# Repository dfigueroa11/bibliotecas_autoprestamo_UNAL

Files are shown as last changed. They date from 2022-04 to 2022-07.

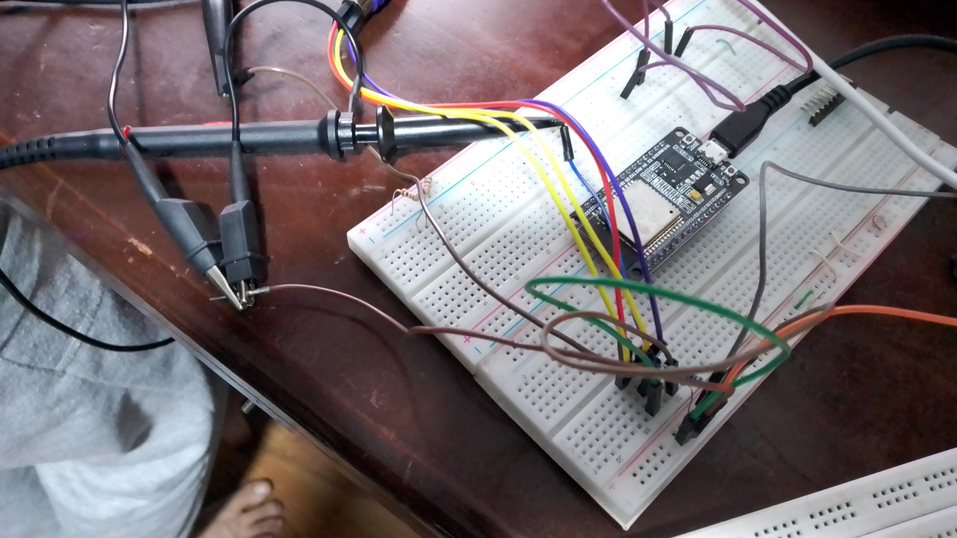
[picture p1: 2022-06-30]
images/teclado_ps_2_prueba.jpg

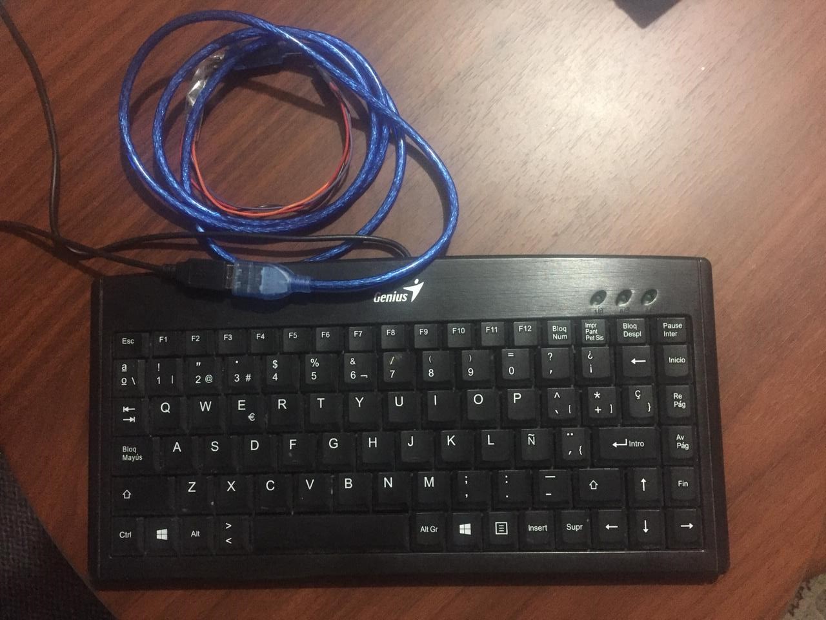
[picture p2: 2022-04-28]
images/reclado_prueba.jpeg

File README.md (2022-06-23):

# Autoprestamo de libros

Sistema de automatización de préstamo y devolución de Libros de las Bibliote dentro del campus de la Universidad Nacional de Colombia, incorporando la conexión entre puntos de prestamo y facilitando el proceso que a la fecha se implementa. El sistema tiene como objetivo principal reducir construir un sistema que pueda ser escalable y replicable de forma más economica.

Integrantes: 
* Maria Alejandra Salgado Herrera
* Emmanuel David Correa Morales
* Ferdy Eduardo Larrotta Ruiz
* Danny Esteban Portela Robayo
* Diego Alejandro Figueroa Del Castillo

## Organización del repositorio

### En la carpeta "[Sensibilizador_PCB](https://github.com/dfigueroa11/bibliotecas_autoprestamo_UNAL/tree/main/Sensibilizador_PCB)" se encuentran los diseños y esquemáticos llevados a cabo en el diseño del Sensibilizador del sistema.
### En la carpeta "[esquematico_ESP32](https://github.com/dfigueroa11/bibliotecas_autoprestamo_UNAL/tree/main/esquematico_ESP32)" se encuentran los diseños y esquemáticos llevados a cabo en el diseño del circuito logico y de control del sistema.
### "[Micropython](https://github.com/dfigueroa11/bibliotecas_autoprestamo_UNAL/tree/main/Micropython)" contiene los scripts utilizados para programar el microcontrolador de la solución.
### En "[Diseno_carcasa](https://github.com/dfigueroa11/bibliotecas_autoprestamo_UNAL/tree/main/Diseno_carcasa)" se encuentran los modelos 3D, planos, DXFs y consideraciones físicas para la carcasa. 
### "[Lista_materiales.xlsx](https://github.com/dfigueroa11/bibliotecas_autoprestamo_UNAL/blob/main/Lista_materiales.xlsx)" contiene la lista de materiales necesarios para el desarrollo del prototipo. 
### "[images](https://github.com/dfigueroa11/bibliotecas_autoprestamo_UNAL/tree/main/images)" almacena las imágenes utilizadas en la documentación y en los archivos readme de cada sección.

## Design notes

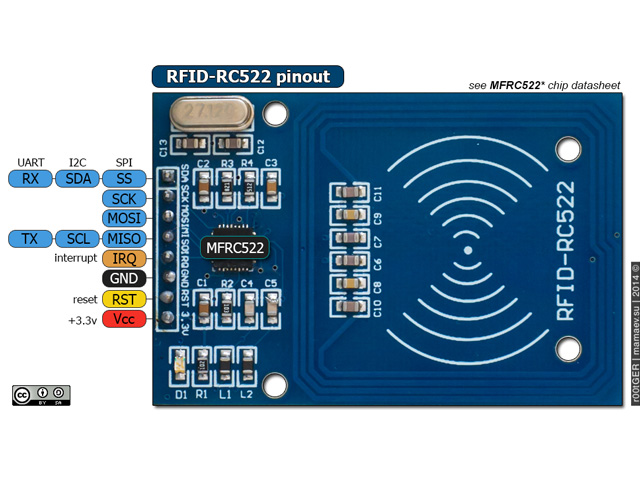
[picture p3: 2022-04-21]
images/modulo-rfid-c522.jpg

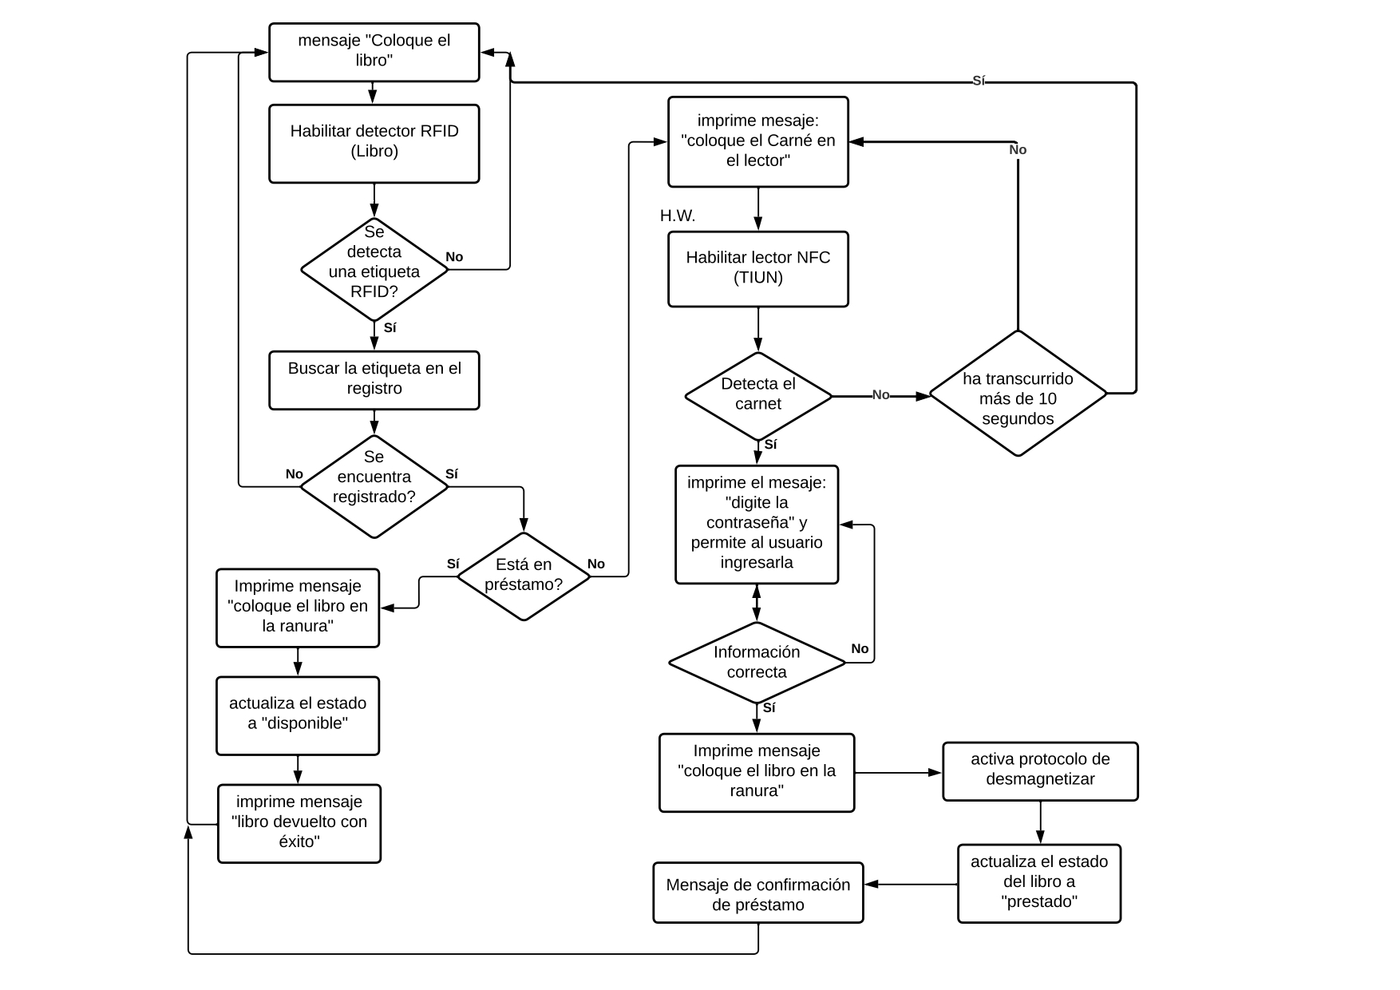
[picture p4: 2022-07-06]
images/diagrama_funcionamiento.jpg

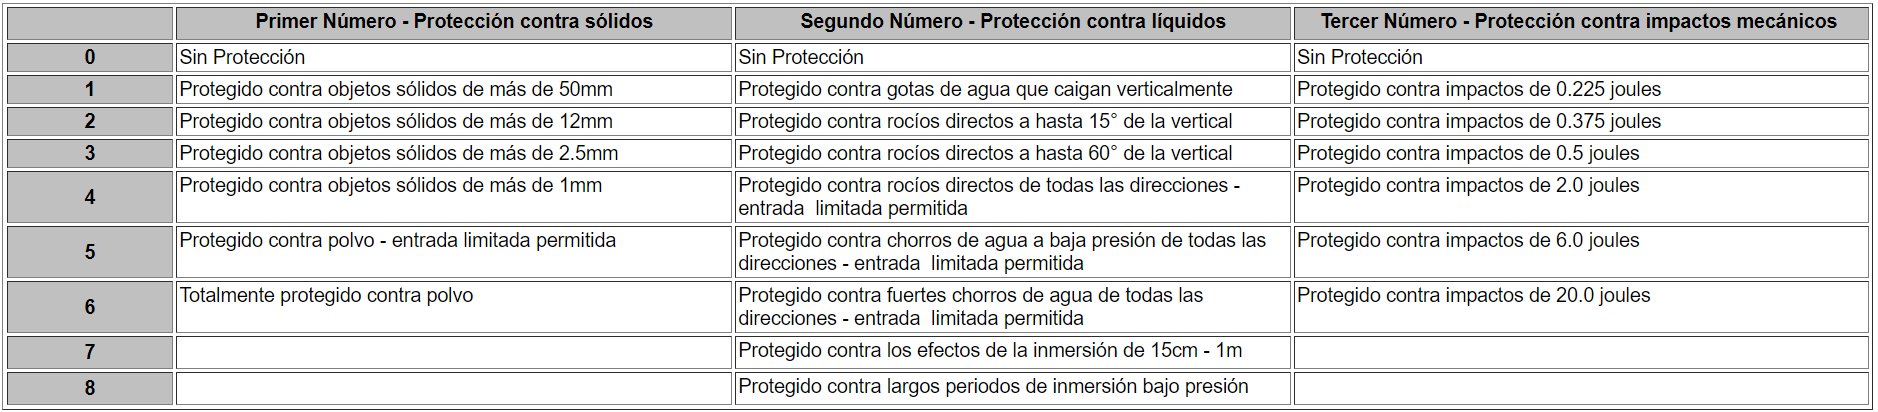
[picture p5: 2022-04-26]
images/IP.PNG

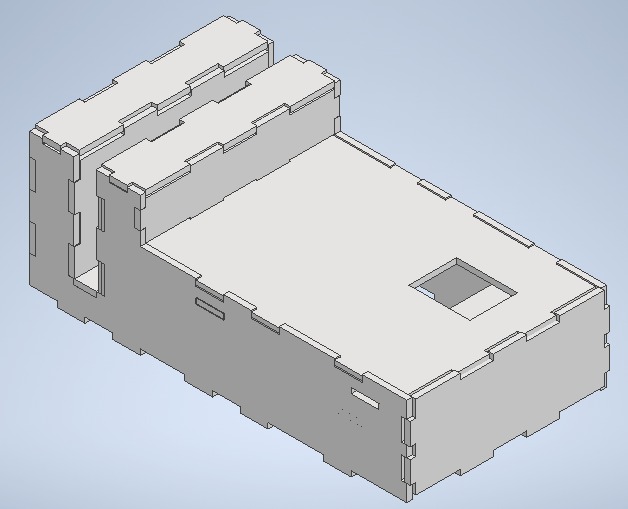
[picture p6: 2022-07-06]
images/carcasa2.jpeg

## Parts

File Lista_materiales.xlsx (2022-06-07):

Ref | Qnty | Value | Cmp name | Footprint | Description | Vendor | Estado del pedido
C1, C4, | 3 | 1uF 50V | C_Polarized | Capacitor_SMD:C_Elec_4x5.4 | Polarized capacitor | Vistrónica | Pedido realizado
C2, C5, | 3 | 100nF 50V | C_Polarized | Capacitor_SMD:C_0603_1608Metric_Pad1.08x0.95mm_HandSolder | Polarized capacitor | Vistrónica | Pedido realizado
C3, C6, | 3 | 10nF 25V | C_Polarized | Capacitor_SMD:C_0805_2012Metric_Pad1.18x1.45mm_HandSolder | Polarized capacitor | Vistrónica | Pedido realizado
D1, D2, D3, D4, D_danny | 5 | F10L60u | D | Package_TO_SOT_THT:TO-220-2_Vertical | Diode | MercadoLibre | Pedido realizado
D5, D6, D7, D8, | 6 | SS34FA | D | Diode_SMD:D_SOD-123 | Diode | Sigma | Pedido realizado
F1, | 2 | porta Fuse | Fuse | Connector:porta_fusible | Fuse | Sigma | Pedido realizado
F1, | 10 | Fuse 8A | Fuse | Connector:porta_fusible | Fuse | Vistrónica | Pedido realizado
L1, | 2 | L | L | Connector:conector Faston macho | Inductor | Vistrónica | Pedido realizado
L1, | 2 | L | L | Connector:conector Faston hembra | Inductor | Vistrónica | Pedido realizado
M1, | 1 | Fan | Fan | Ventilador 12 V | Fan | Vistrónica | Pedido realizado
Q1, Q2, Q3, Q4, | 6 | IRF630 | Q_NMOS_GDS | Package_TO_SOT_THT:TO-220-3_Vertical | N-MOSFET transistor, gate/drain/source | Sigma | Pedido realizado
Q5, | 1 | 2300 | Q_NMOS_GSD | Package_TO_SOT_SMD:SOT-23 | N-MOSFET transistor, gate/source/drain | Vistrónica | Pedido realizado
R1, R5, | 3 | 75k | R | Resistor_SMD:R_0805_2012Metric_Pad1.20x1.40mm_HandSolder | Resistor | Vistrónica | Pedido realizado
R2, R3, R4, R6, R7, R8, R9, R10, | 12 | 2.74 1/4W | R | Resistor_SMD:R_1206_3216Metric_Pad1.30x1.75mm_HandSolder | Resistor | Sigma | Pedido realizado
U1, U2, | 2 | LM5104M | LM5104M | Package_SO:SOIC-8_3.9x4.9mm_P1.27mm | Driver mosfet | MercadoLibre | Pedido realizado
Vin_J2, Vout_J1, Vin | 3 | Jack_in | Jack-DC | Connector_BarrelJack:BarrelJack_Horizontal | DC Barrel Jack | Vistrónica | Pedido realizado
cable jack jack | 1 | cable | cable | cable | cable | Vistrónica | Pedido realizado
Adaptador 12V 10A | 1 | adaptador | adaptador | adaptador | adaptador | MercadoLibre | Pedido realizado
Boot1, enable | 2 | SW_Push | SW_Push | Button_Switch_SMD:SW_SPST_CK_RS282G05A3 | Push button switch, generic, two pins | Sigma | Pedido realizado
C1, C2, | 2 | 1nf | C | Capacitor_SMD:C_0805_2012Metric_Pad1.18x1.45mm_HandSolder | Unpolarized capacitor | Sigma | Pedido realizado
C4, C7, C3 | 3 | 100n | C | Capacitor_SMD:C_0805_2012Metric_Pad1.18x1.45mm_HandSolder | Unpolarized capacitor | Vistrónica | Pedido realizado
C5, | 1 | 10u | C | Capacitor_SMD:C_0805_2012Metric_Pad1.18x1.45mm_HandSolder | Unpolarized capacitor | Vistrónica | Pedido realizado
C6, | 1 | 22u | C | Capacitor_SMD:C_0805_2012Metric_Pad1.18x1.45mm_HandSolder | Unpolarized capacitor | Vistrónica | Pedido realizado
C8, | 1 | 470u | C_Polarized | Capacitor_SMD:CP_Elec_8x6.9 | Polarized capacitor | Vistrónica | Pedido realizado
C10, | 1 | 220u | C_Polarized | Capacitor_SMD:CP_Elec_6.3x7.7 | Polarized capacitor | Vistrónica | Pedido realizado
D1, D2, D3, | 3 | LED | LED | LED_SMD:LED_0805_2012Metric_Pad1.15x1.40mm_HandSolder | Light emitting diode | ya se tienen | ya se tienen
D4, | 1 | 1N5825 | DIODE | Diode_THT:D_DO-201AE_P5.08mm_Vertical_AnodeUp | diodo | Sigma | Pedido realizado
FB1, FB2, | 2 | FerriteBead | FerriteBead | Resistor_SMD:R_0603_1608Metric_Pad0.98x0.95mm_HandSolder | Ferrite bead | MercadoLibre | Pedido realizado
L1, | 1 | 68u | L | Inductor_SMD:L_Neosid_SM-PIC0612H | Inductor | MercadoLibre | Pedido realizado
Program1, | 1 | Conn_01x05_Female | Conn_01x05_Female | Connector_PinSocket_2.54mm:PinSocket_1x05_P2.54mm_Vertical |  | Sigma | Pedido realizado
Q1, Q2, | 2 | BSS138 | BSS138 | Package_TO_SOT_SMD:SOT-23 | 50V Vds, 0.22A Id, N-Channel MOSFET, SOT-23 | Vistrónica | Pedido realizado
R1,R2,R6, R7, R8, R9, | 6 | 10k | R | Resistor_SMD:R_0805_2012Metric_Pad1.20x1.40mm_HandSolder | Resistor | Vistrónica | Pedido realizado
R3, R4, R5 | 3 | R | R | Resistor_SMD:R_0805_2012Metric_Pad1.20x1.40mm_HandSolder | Resistor | ya se tienen | ya se tienen
Teclado1, | 1 | USB_A | USB_A | Connector_USB:USB_A_Molex_67643_Horizontal | USB Type A connector | Vistrónica | Pedido realizado
U1, | 1 | ESP32-WROOM-32 | ESP32-WROOM-32 | RF_Module:ESP32-WROOM-32 | esp32 | Vistrónica | Pedido realizado
U2, | 1 | LM1117-3.3 | LM1117-3.3 | Package_TO_SOT_SMD:TO-252-2 | regulador | Sigma | Pedido realizado
U3, | 1 | LM2596S-5 | LM2596S-5 | Package_TO_SOT_SMD:TO-263-5_TabPin3 | buck converter | MercadoLibre | Pedido realizado
M1, | 1 | Fan conn | Fan conn | Connector_JST:JST_EH_B2B-EH-A_1x02_P2.50mm_Vertical | JST | MercadoLibre | Falta pedirlo
J3, Sensitizer1, | 2 | Conn_inputs | Conn_01x04_Male | Connector_JST:JST_EH_S4B-EH_1x04_P2.50mm_Horizontal | JST | MercadoLibre | Falta pedirlo
RFID1, RFID2 | 1 | J2 | Conn_01x08_Male | Connector_JST:JST_EH_S8B-EH_1x08_P2.50mm_Horizontal | JST | MercadoLibre | Falta pedirlo
screen1 conn | 1 | J5 | Conn_01x10_Male | Connector_JST:JST_EH_S10B-EH_1x10_P2.50mm_Horizontal | JST | MercadoLibre | Falta pedirlo
pantalla | 1 | pantalla | pantalla | pantalla | pantalla | MercadoLibre | Pedido realizado

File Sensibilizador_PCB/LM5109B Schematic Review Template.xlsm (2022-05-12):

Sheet: Start Here
Texas Instruments
LM510xx Schematic and Layout Checklist
Instructions: Select device on selection page. Use this document as a supplemental checklist to be used with the driver's datasheet.

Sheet: Selection
Device | LM5104
 |  | Typical Application Schematic

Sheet: Checklist
System | Component | Purpose | Component required | Typical Value | Additional Considerations | Connections | Layout Recommendation | Check if Complete | Comments
Bootstrap | Cboot | Build charge to drive high side gate | Yes | Based on system specs | 25V , MLCC, X7R recommended | HS, HB | Place close to HS, HB pins | Used & Complete | 10nF 25V
 | Rboot | limit Dboot current | No | 1Ω - 20Ω |  | HB, Dboot | minimize path length from supply to Cboot | Not Used & Complete
 | Dboot | Reduce recovery time | No |  | High Voltage(Voltage rating should be higher than the DC link), fast recovery diode or SiC Schottky diode with a low forward drop voltage and low junction capacitance | Rboot, VDD | minimize path length from supply to Cboot | Not Used & Complete
Power supply | Large Bypass cap | reduce VDD drop at switch on | Yes | >1μF | 50V , MLCC, X7R recommended | VDD,GND | place as close to VDD pin as possible, connect to large ground plane | Used & Complete | 2.7uF 50V
 | Small Bypass cap | reduce noise on VDD pin | Yes | >100nF | 50V , MLCC, X7R recommended | VDD,GND | Place close to VDD, connect to large ground plane | Used & Complete | 120nF 50V
Dead Time Selection | dead time resistor | Dead time selection | Yes | 5kΩ - 100kΩ |  | RT/RDT,GND | Close to RDT pin | Open
 | HO dead time resistor | High side output delay selection | Yes | 5kΩ - 100kΩ |  | RT1,GND | Close to RT1 | Used & Complete | por definir
 | LO dead time resistor | Low side output delay selection | Yes | 5kΩ - 100kΩ |  | RT2,GND | Close to RT2 | Used & Complete
Input filtering | HI Resistor | filter input noise | No | 0Ω - 100Ω |  | HI, Input | Place close to HI pin | Not Used & Complete
 | HI Cap | filter input noise | No | 10pF-100pF |  | HI, GND | Place close to HI pin, to large ground plane | Not Used & Complete
 | EN Resistor | filter input noise | No | 0Ω - 100Ω |  | EN, Input | Place close to IN pin | Open
 | EN Cap | filter input noise | No | 10pF-100pF |  | EN, GND | Place close to IN pin, to large ground plane | Open
 | IN Resistor | filter input noise | No | 0Ω - 100Ω |  | IN, Input | Place close to IN pin | Open
 | IN Cap | filter input noise | No | 10pF-100pF |  | IN, GND | Place close to IN pin, to large ground plane | Open
 | LI Resistor | filter input noise | No | 0Ω - 100Ω |  | LI, Input | Place close to LI pin | Not Used & Complete
 | LI Cap | filter input noise | No | 10pF-100pF |  | LI, GND | Place close to LI pin, to large ground plane | Not Used & Complete
Outputs | Ron HO | reduce switching speed | Yes | 0 - 5Ω |  | HO, High gate | Place as close to the gate as possible in order to minimize groud loop | Used & Complete
 | Ron LO | reduce switching speed | Yes | 0 - 5Ω |  | LO, Low Gate | Place as close to the gate as possible in order to minimize groud loop | Used & Complete
 | Roff HO | control switch off speed | No | 0 - 5Ω |  | HO, Doff HO | Place as close to the gate as possible in order to minimize groud loop | Used & Complete
 | Roff LO | control switch off speed | No | 0 - 5Ω |  | LO, Doff LO | Place as close to the gate as possible in order to minimize groud loop | Used & Complete
 | Doff HO | increase switch off speed | No |  |  | High Gate, Roff HO | Place close to gate | Used & Complete
 | Doff LO | increase switch off speed | No |  |  | Low Gate, Roff LO | Place close to gate | Used & Complete
 | Rgs HO | reduce gate ripple | No | 5.1kΩ - 20kΩ |  | High Gate, GND | Place as close to the gate as possible | Not Used & Complete
 | Rgs LO | reduce gate ripple | No | 5.1kΩ - 20kΩ |  | Low Gate, GND | Place as close to the gate as possible | Not Used & Complete
 | Dclamp HO | reduce gate ripple | No |  | Schottky | High Gate, HS | Place close to drive pin | Not Used & Complete
 | Dclamp LO | reduce gate ripple | No |  | Schottky | Low Gate, GND | Place close to drive pin | Not Used & Complete

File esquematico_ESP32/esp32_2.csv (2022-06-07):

Source: | /Users/diegofigueroa/Documents/GitHub/bibliotecas_autoprestamo_UNAL/esquematico_ESP32/esp32_2.kicad_sch
Date: | 2022 June 03, Friday 09:22:31
Tool: | Eeschema (6.0.5-0)
Generator: | /Applications/KiCad/KiCad.app/Contents/SharedSupport/plugins/bom_csv_grouped_by_value_with_fp.py
Component Count: | 39
Ref | Qnty | Value | Cmp name | Footprint | Description | Vendor
Boot1, | 1 | SW_Push | SW_Push | Button_Switch_SMD:SW_SPST_CK_RS282G05A3 | Push button switch, generic, two pins
C1, C2, | 2 | 1nf | C | Capacitor_SMD:C_0805_2012Metric_Pad1.18x1.45mm_HandSolder | Unpolarized capacitor
C3, | 1 | 100u | C_Polarized | Capacitor_SMD:C_0805_2012Metric_Pad1.18x1.45mm_HandSolder | Polarized capacitor
C4, C7, | 2 | 100n | C | Capacitor_SMD:C_0805_2012Metric_Pad1.18x1.45mm_HandSolder | Unpolarized capacitor
C5, | 1 | 10u | C | Capacitor_SMD:C_0805_2012Metric_Pad1.18x1.45mm_HandSolder | Unpolarized capacitor
C6, | 1 | 22u | C | Capacitor_SMD:C_0805_2012Metric_Pad1.18x1.45mm_HandSolder | Unpolarized capacitor
C8, | 1 | 470u | C_Polarized | Capacitor_SMD:CP_Elec_8x6.9 | Polarized capacitor
C10, | 1 | 220u | C_Polarized | Capacitor_SMD:CP_Elec_6.3x7.7 | Polarized capacitor
D1, D2, D3, | 3 | LED | LED | LED_SMD:LED_0805_2012Metric_Pad1.15x1.40mm_HandSolder | Light emitting diode
D4, | 1 | 1N5825 | DIODE | Diode_THT:D_DO-201AE_P5.08mm_Vertical_AnodeUp | Diode symbol for simulation only. Pin order incompatible with official kicad footprints
FB1, FB2, | 2 | FerriteBead | FerriteBead | Resistor_SMD:R_0603_1608Metric_Pad0.98x0.95mm_HandSolder | Ferrite bead
L1, | 1 | 68u | L | Inductor_SMD:L_Neosid_SM-PIC0612H | Inductor
Program1, | 1 | Conn_01x05_Female | Conn_01x05_Female | Connector_PinSocket_2.54mm:PinSocket_1x05_P2.54mm_Vertical | Generic connector, single row, 01x05, script generated (kicad-library-utils/schlib/autogen/connector/)
Q1, Q2, | 2 | BSS138 | BSS138 | Package_TO_SOT_SMD:SOT-23 | 50V Vds, 0.22A Id, N-Channel MOSFET, SOT-23
R1, R2, R3, R4, R5, R6, R7, R8, R9, | 9 | 10k | R | Resistor_SMD:R_0805_2012Metric_Pad1.20x1.40mm_HandSolder | Resistor
RFID1, | 1 | J2 | Conn_01x08_Male | Connector_JST:JST_EH_S8B-EH_1x08_P2.50mm_Horizontal | Generic connector, single row, 01x08, script generated (kicad-library-utils/schlib/autogen/connector/)
RFID2, | 1 | J3 | Conn_01x08_Male | Connector_JST:JST_EH_S8B-EH_1x08_P2.50mm_Horizontal | Generic connector, single row, 01x08, script generated (kicad-library-utils/schlib/autogen/connector/)
Rst1, | 1 | Enable | SW_Push | Button_Switch_SMD:SW_SPST_CK_RS282G05A3 | Push button switch, generic, two pins
screen1, | 1 | J5 | Conn_01x10_Male | Connector_JST:JST_EH_S10B-EH_1x10_P2.50mm_Horizontal | Generic connector, single row, 01x10, script generated (kicad-library-utils/schlib/autogen/connector/)
Sensitizer1, | 1 | Conn_01x04_Female | Conn_01x04_Female | Connector_JST:JST_EH_S4B-EH_1x04_P2.50mm_Horizontal | Generic connector, single row, 01x04, script generated (kicad-library-utils/schlib/autogen/connector/)
Teclado1, | 1 | USB_A | USB_A | Connector_USB:USB_A_Molex_67643_Horizontal | USB Type A connector
U1, | 1 | ESP32-WROOM-32 | ESP32-WROOM-32 | RF_Module:ESP32-WROOM-32 | RF Module, ESP32-D0WDQ6 SoC, Wi-Fi 802.11b/g/n, Bluetooth, BLE, 32-bit, 2.7-3.6V, onboard antenna, SMD
U2, | 1 | LM1117-3.3 | LM1117-3.3 | Package_TO_SOT_SMD:TO-252-2 | 800mA Low-Dropout Linear Regulator, 3.3V fixed output, TO-220/TO-252/TO-263/SOT-223
U3, | 1 | LM2596S-5 | LM2596S-5 | Package_TO_SOT_SMD:TO-263-5_TabPin3 | 5V 3A Step-Down Voltage Regulator, TO-263
Vin1, | 1 | Jack-DC | Jack-DC | Connector_BarrelJack:BarrelJack_Horizontal | DC Barrel Jack

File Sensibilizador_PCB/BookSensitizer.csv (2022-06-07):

Source: | /Users/diegofigueroa/Documents/GitHub/bibliotecas_autoprestamo_UNAL/Sensibilizador_PCB/BookSensitizer.kicad_sch
Date: | 2022 June 02, Thursday 15:05:15
Tool: | Eeschema (6.0.5-0)
Generator: | /Applications/KiCad/KiCad.app/Contents/SharedSupport/plugins/bom_csv_grouped_by_value_with_fp.py
Component Count: | 37
Ref | Qnty | Value | Cmp name | Footprint | Description | Vendor
C1, C4, | 2 | 1uF 50V | C_Polarized | Capacitor_SMD:C_Elec_4x5.4 | Polarized capacitor
C2, C5, | 2 | 100nF 50V | C_Polarized | Capacitor_SMD:C_0603_1608Metric_Pad1.08x0.95mm_HandSolder | Polarized capacitor
C3, C6, | 2 | 10nF 25V | C_Polarized | Capacitor_SMD:C_0805_2012Metric_Pad1.18x1.45mm_HandSolder | Polarized capacitor
D1, D2, D3, D4, | 4 | F10L60u | D | Package_TO_SOT_THT:TO-220-2_Vertical | Diode
D5, D6, D7, D8, | 4 | SS34FA | D | Diode_SMD:D_SOD-123 | Diode
F1, | 1 | Fuse | Fuse | Connector:porta_fusible | Fuse
J3, | 1 | Conn_inputs | Conn_01x04_Male | Connector_JST:JST_EH_S4B-EH_1x04_P2.50mm_Horizontal | Generic connector, single row, 01x04, script generated (kicad-library-utils/schlib/autogen/connector/)
L1, | 1 | L | L | Connector:conector Faston | Inductor
M1, | 1 | Fan | Fan | Connector_JST:JST_EH_B2B-EH-A_1x02_P2.50mm_Vertical | Fan
Q1, Q2, Q3, Q4, | 4 | IRF630 | Q_NMOS_GDS | Package_TO_SOT_THT:TO-220-3_Vertical | N-MOSFET transistor, gate/drain/source
Q5, | 1 | SI2302 | Q_NMOS_GSD | Package_TO_SOT_SMD:SOT-23 | N-MOSFET transistor, gate/source/drain
R1, R5, | 2 | R | R | Resistor_SMD:R_0805_2012Metric_Pad1.20x1.40mm_HandSolder | Resistor
R2, R3, R4, R6, R7, R8, R9, R10, | 8 | 2.74 1/4W | R | Resistor_SMD:R_1206_3216Metric_Pad1.30x1.75mm_HandSolder | Resistor
U1, U2, | 2 | LM5104M | LM5104M | Package_SO:SOIC-8_3.9x4.9mm_P1.27mm
Vin_J2, | 1 | Jack_in | Jack-DC | Connector_BarrelJack:BarrelJack_Horizontal | DC Barrel Jack
Vout_J1, | 1 | Jack_out | Jack-DC | Connector_BarrelJack:BarrelJack_Horizontal | DC Barrel Jack

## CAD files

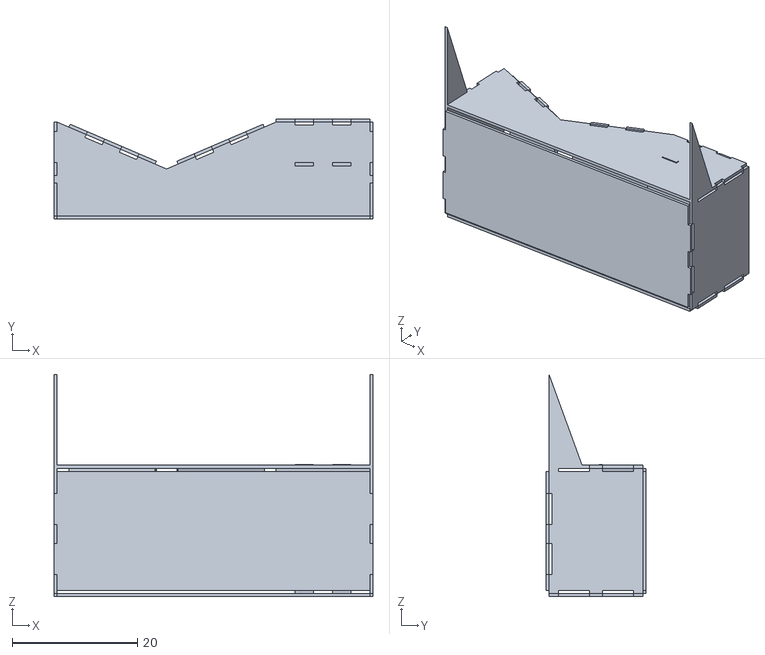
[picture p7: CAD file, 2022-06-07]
carcasa final/Caja 1.0/Ensamble caja.stl
51.0 x 16.0 x 35.5

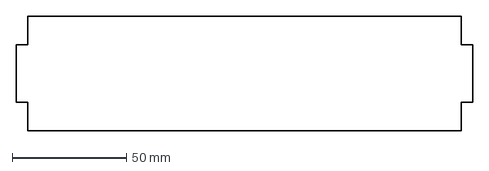
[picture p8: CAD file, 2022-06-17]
carcasa final/Caja 1.0/DXfs/Top1.dxf
200.0 x 50.0 mm

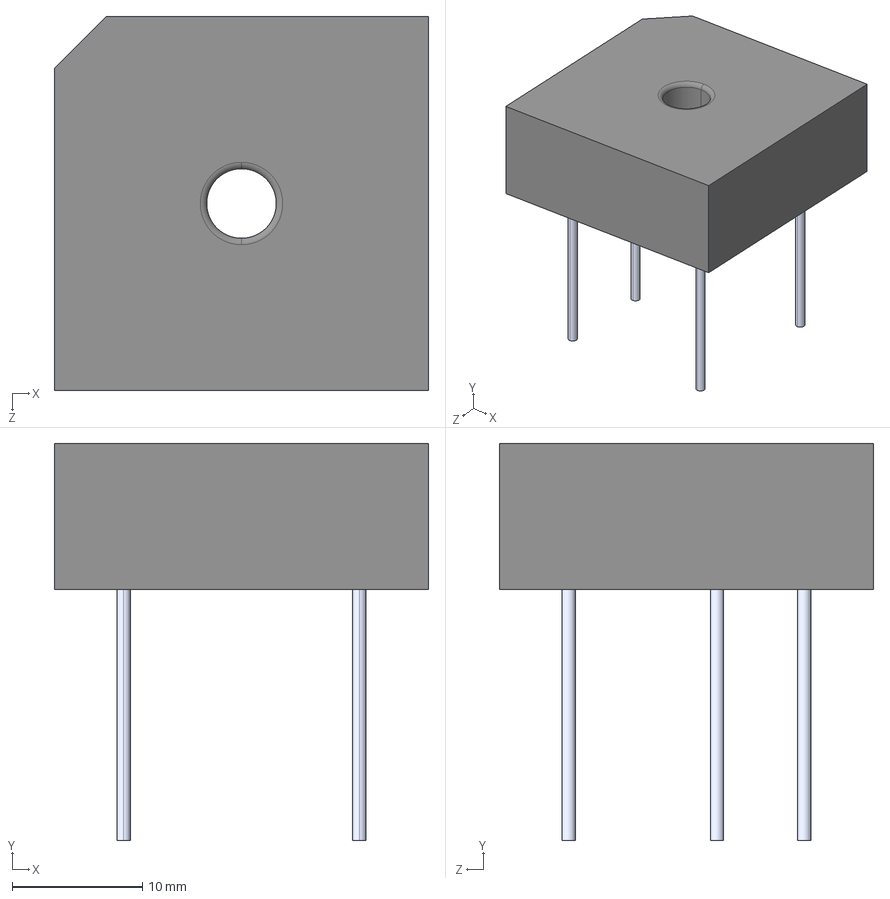
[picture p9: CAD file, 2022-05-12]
Sensibilizador_PCB/GBPC3506/GBPC3506.step
28.8 x 30.5 x 28.8 mm

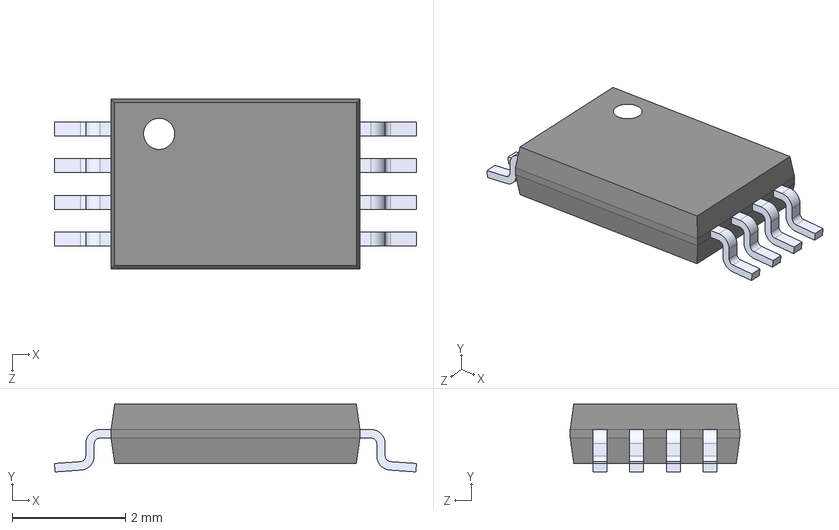
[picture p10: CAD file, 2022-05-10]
Sensibilizador_PCB/LibreriaLM5104/LM5104M.step
6.40 x 1.20 x 3.00 mm

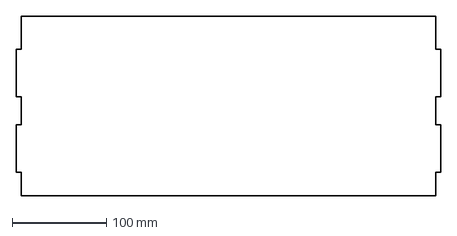
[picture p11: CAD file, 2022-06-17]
carcasa final/Caja 1.0/DXfs/PIsp.dxf
450.0 x 190.0 mm

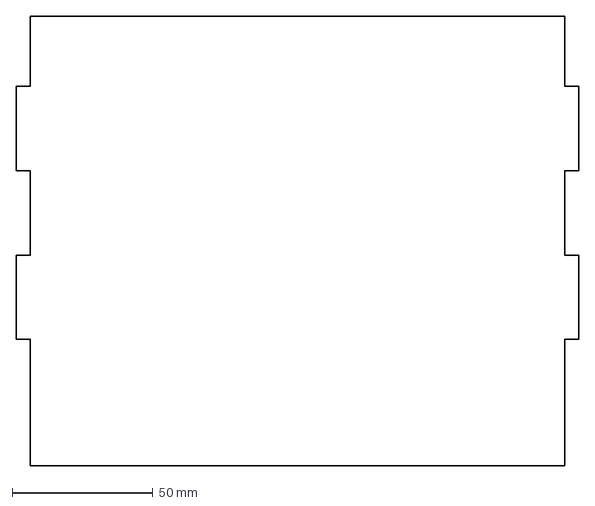
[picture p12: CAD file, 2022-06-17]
carcasa final/Caja 1.0/DXfs/Top diagonal.dxf
200.0 x 160.0 mm

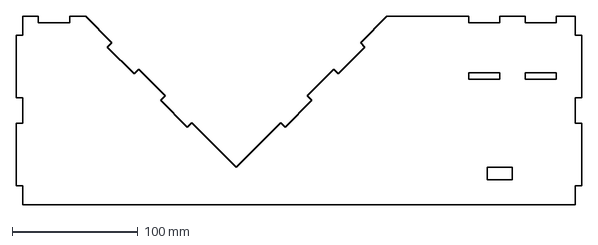
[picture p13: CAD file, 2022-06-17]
carcasa final/Caja 1.0/DXfs/Frontal.dxf
450.0 x 150.0 mm

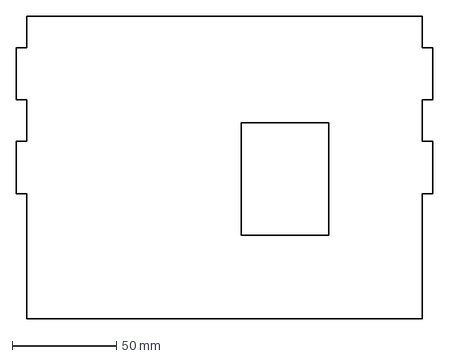
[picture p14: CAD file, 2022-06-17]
carcasa final/Caja 1.0/DXfs/Top 2.dxf
200.0 x 145.0 mm

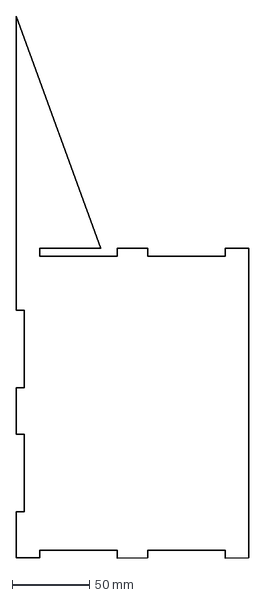
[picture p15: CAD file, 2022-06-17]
carcasa final/Caja 1.0/DXfs/Laterales.dxf
150.0 x 350.0 mm

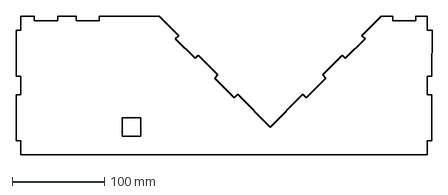
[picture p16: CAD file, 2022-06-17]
carcasa final/Caja 1.0/DXfs/Posterior.dxf
450.0 x 150.0 mm

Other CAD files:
carcasa final/Caja 1.0/Ensamble caja.iam
carcasa final/Caja 1.0/Fondo.ipt
carcasa final/Caja 1.0/Frontal.ipt
carcasa final/Caja 1.0/Lateral.ipt
carcasa final/Caja 1.0/Modelo base.ipt
carcasa final/Caja 1.0/OldVersions/Ensamble caja.0005.iam
carcasa final/Caja 1.0/OldVersions/Fondo.0003.ipt
carcasa final/Caja 1.0/OldVersions/Frontal.0004.ipt
carcasa final/Caja 1.0/OldVersions/Lateral.0001.ipt
carcasa final/Caja 1.0/OldVersions/Modelo base.0004.ipt
carcasa final/Caja 1.0/OldVersions/Piso.0003.ipt
carcasa final/Caja 1.0/OldVersions/Tapa diagonal.0001.ipt
carcasa final/Caja 1.0/OldVersions/Top 1.0001.ipt
carcasa final/Caja 1.0/Part4.ipt
carcasa final/Caja 1.0/Piso.ipt
carcasa final/Caja 1.0/Tapa diagonal.ipt
carcasa final/Caja 1.0/Top 1.ipt
carcasa final/Caja 1.0/Top 2.ipt
carcasa final/Caja 2.0/Ensamble caja.iam
carcasa final/Caja 2.0/Frontal.ipt
carcasa final/Caja 2.0/LAT 4.ipt
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

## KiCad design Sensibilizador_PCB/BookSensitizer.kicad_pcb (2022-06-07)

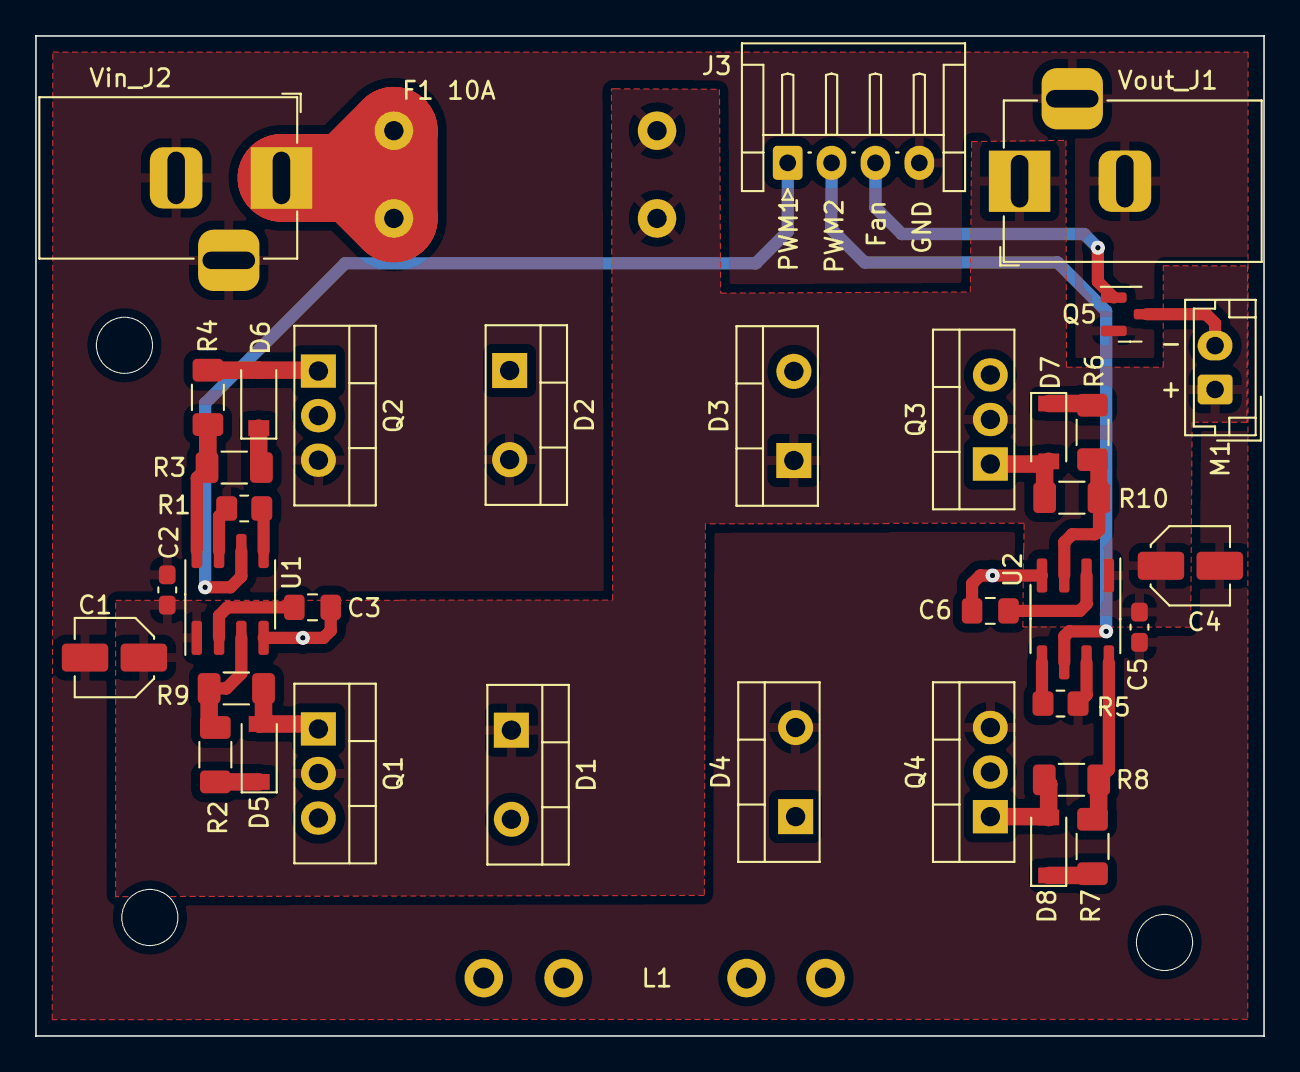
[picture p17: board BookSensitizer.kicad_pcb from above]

Board: 2 copper layers, 70.0 x 57.0 mm, 40 parts (0 on the bottom side), 25 nets.

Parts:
C1, C4: 1uF 50V; C_Elec_4x5.4
C2, C5: 100nF 50V; C_0603_1608Metric_Pad1.08x0.95mm_HandSolder
C3, C6: 10nF 25V; C_0805_2012Metric_Pad1.18x1.45mm_HandSolder
D1, D2, D3, D4: F10L60u; TO-220-2_Vertical
D5, D6, D7, D8: SS34FA; D_SOD-123
F1 10A: Fuse; porta_fusible
J3: Conn_inputs; JST_EH_S4B-EH_1x04_P2.50mm_Horizontal
L1: L; conector Faston
M1: Fan; JST_EH_B2B-EH-A_1x02_P2.50mm_Vertical
Q1, Q2, Q3, Q4: IRF630; TO-220-3_Vertical
Q5: SI2302; SOT-23
R1, R5: R; R_0805_2012Metric_Pad1.20x1.40mm_HandSolder
R2, R3, R4, R6, R7, R8, R9, R10: 2.74 1/4W; R_1206_3216Metric_Pad1.30x1.75mm_HandSolder
T1, T2, T3: MountingHole_3.2mm_M3
U1, U2: LM5104M; SOIC-8_3.9x4.9mm_P1.27mm
Vin_J2: Jack_in; BarrelJack_Horizontal
Vout_J1: Jack_out; BarrelJack_Horizontal

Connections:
+12V: C1.1, C2.1, C4.1, C5.1, D1.1 (K), D3.1 (K), F1 10A.2, M1.1 (+), Q1.2 (D), Q3.2 (D), U1.1 (VDD), U2.1 (VDD), Vout_J1.1
/driver1/G_High: D5.2 (A), Q1.1 (G), R9.2
/driver1/G_low: D6.2 (A), Q2.1 (G), R4.2
/driver1/Hs: C3.2, D1.2 (A), D2.1 (K), L1.1, Q1.3 (S), Q2.2 (D), U1.4 (HS)
/driver2/G_High: D7.2 (A), Q3.1 (G), R10.2
/driver2/G_low: D8.2 (A), Q4.1 (G), R8.2
/driver2/Hs: C6.2, D3.2 (A), D4.1 (K), L1.2, Q3.3 (S), Q4.2 (D), U2.4 (HS)
/in_1: J3.1, U1.6 (LI)
/in_2: J3.2, U2.6 (LI)
/in_3: J3.3, Q5.1 (G)
GND: C1.2, C2.2, C4.2, C5.2, D2.2 (A), D4.2 (A), J3.4, Q2.3 (S), Q4.3 (S), Q5.2 (S), R1.2, R5.2, U1.7 (VSS), U2.7 (VSS), Vin_J2.2, Vout_J1.2
unnamed: C3.1, U1.2 (HB)
unnamed: C6.1, U2.2 (HB)
unnamed: D5.1 (K), R2.2
unnamed: D6.1 (K), R3.2
unnamed: D7.1 (K), R6.2
unnamed: D8.1 (K), R7.2
unnamed: F1 10A.1, Vin_J2.1
unnamed: M1.2 (-), Q5.3 (D)
unnamed: R1.1, U1.5 (RT)
unnamed: R2.1, R9.1, U1.3 (HO)
unnamed: R3.1, R4.1, U1.8 (LO)
unnamed: R5.1, U2.5 (RT)
unnamed: R6.1, R10.1, U2.3 (HO)
unnamed: R7.1, R8.1, U2.8 (LO)

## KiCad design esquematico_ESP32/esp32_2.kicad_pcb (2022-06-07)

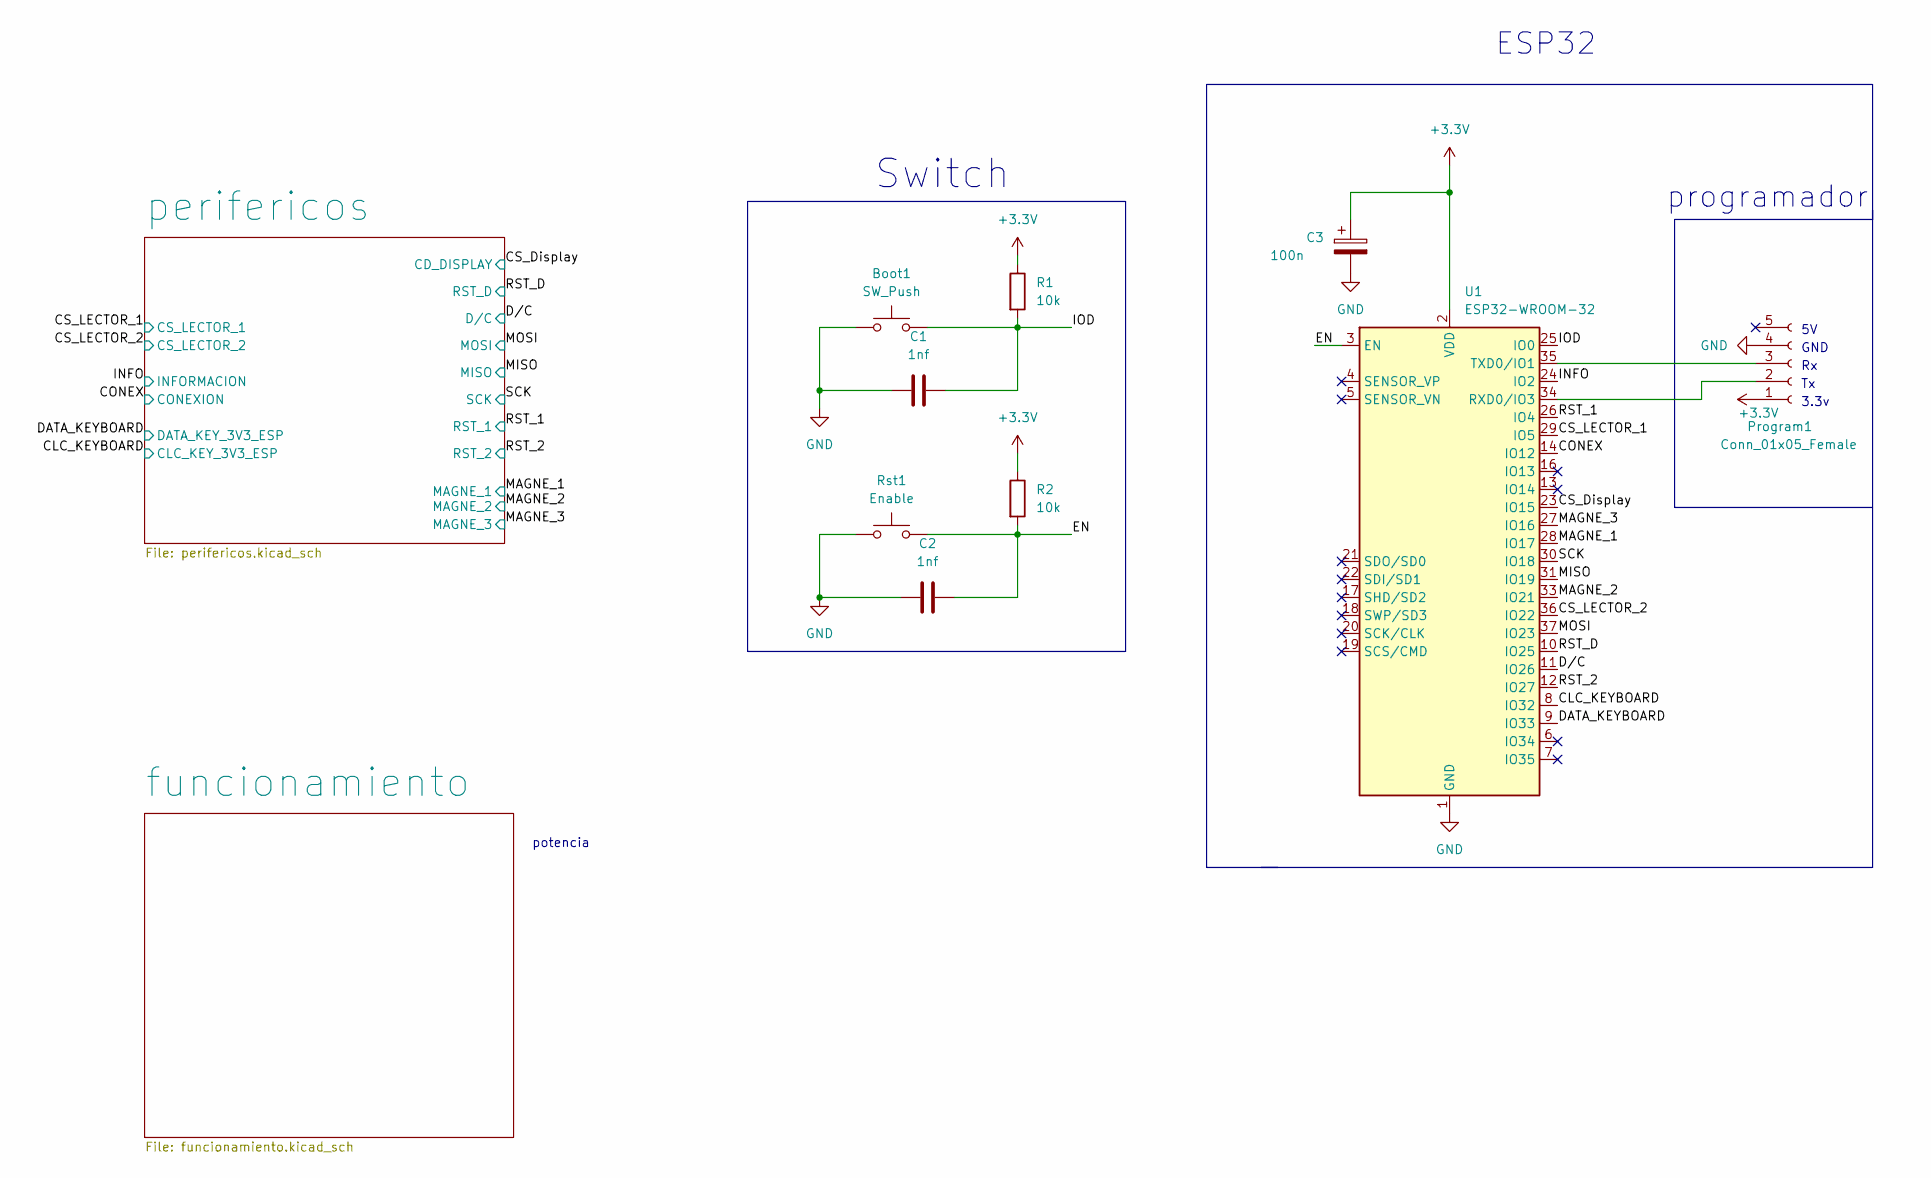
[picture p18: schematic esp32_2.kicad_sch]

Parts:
Boot1: SW_Push; SW_SPST_CK_RS282G05A3
C1, C2: 1nf; C_0805_2012Metric_Pad1.18x1.45mm_HandSolder
C3: 100n; C_0805_2012Metric_Pad1.18x1.45mm_HandSolder
Program1: Conn_01x05_Female; PinSocket_1x05_P2.54mm_Vertical
R1, R2: 10k; R_0805_2012Metric_Pad1.20x1.40mm_HandSolder
Rst1: Enable; SW_SPST_CK_RS282G05A3
U1: ESP32-WROOM-32

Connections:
+3V3: C3.1, Program1.1, R1.1, R2.1, U1.2 (VDD); also elsewhere on the board
/CLC_KEYBOARD: U1.8 (IO32); also elsewhere on the board
/CONEX: U1.14 (IO12); also elsewhere on the board
/CS_Display: U1.23 (IO15); also elsewhere on the board
/CS_LECTOR_1: U1.29 (IO5); also elsewhere on the board
/CS_LECTOR_2: U1.36 (IO22); also elsewhere on the board
/DATA_KEYBOARD: U1.9 (IO33); also elsewhere on the board
/D/C: U1.11 (IO26); also elsewhere on the board
/EN: C2.2, R2.2, Rst1.2, U1.3 (EN)
/INFO: U1.24 (IO2); also elsewhere on the board
/IOD: Boot1.2, C1.2, R1.2, U1.25 (IO0)
/MAGNE_1: U1.28 (IO17); also elsewhere on the board
/MAGNE_2: U1.33 (IO21); also elsewhere on the board
/MAGNE_3: U1.27 (IO16); also elsewhere on the board
/MISO: U1.31 (IO19); also elsewhere on the board
/MOSI: U1.37 (IO23); also elsewhere on the board
/RST_1: U1.26 (IO4); also elsewhere on the board
/RST_2: U1.12 (IO27); also elsewhere on the board
/RST_D: U1.10 (IO25); also elsewhere on the board
/SCK: U1.30 (IO18); also elsewhere on the board
GND: Boot1.1, C1.1, C2.1, C3.2, Program1.4, Rst1.1, U1.1 (GND), U1.15 (GND), U1.38 (GND), U1.39 (GND); also elsewhere on the board
unnamed: Program1.2, U1.34 (RXD0/IO3)
unnamed: Program1.3, U1.35 (TXD0/IO1)

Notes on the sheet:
GND
potencia
Switch
ESP32
programador
3.3v

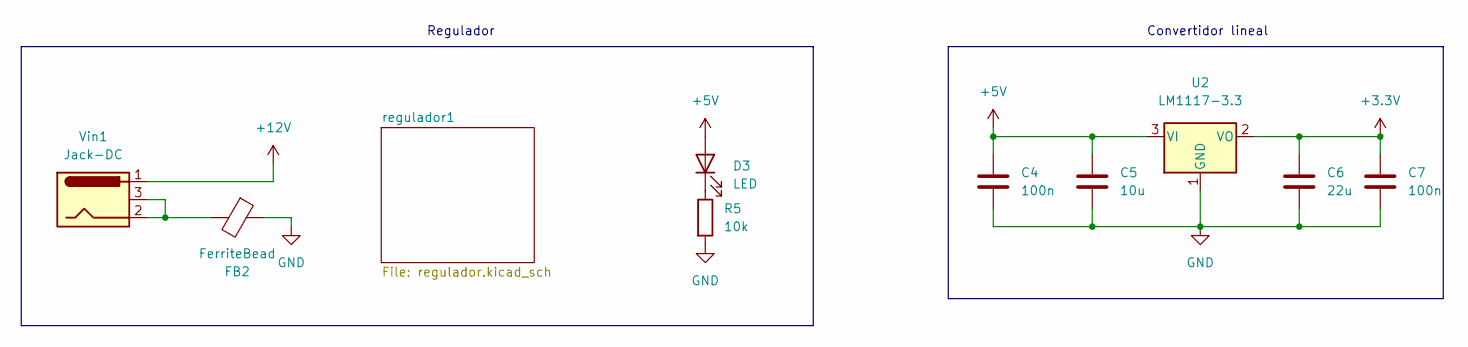
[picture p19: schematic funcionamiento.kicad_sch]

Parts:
C4, C7: 100n; C_0805_2012Metric_Pad1.18x1.45mm_HandSolder
C5: 10u; C_0805_2012Metric_Pad1.18x1.45mm_HandSolder
C6: 22u; C_0805_2012Metric_Pad1.18x1.45mm_HandSolder
D3: LED; LED_0805_2012Metric_Pad1.15x1.40mm_HandSolder
FB2: FerriteBead; R_0603_1608Metric_Pad0.98x0.95mm_HandSolder
R5: 10k; R_0805_2012Metric_Pad1.20x1.40mm_HandSolder
U2: LM1117-3.3; TO-252-2
Vin1: Jack-DC; BarrelJack_Horizontal

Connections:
+3V3: C6.1, C7.1, U2.2 (VO); also elsewhere on the board
+5V: C4.1, C5.1, D3.2 (A), U2.3 (VI); also elsewhere on the board
+12V: Vin1.1; also elsewhere on the board
GND: C4.2, C5.2, C6.2, C7.2, FB2.1, R5.2, U2.1 (GND); also elsewhere on the board
unnamed: D3.1 (K), R5.1
unnamed: FB2.2, Vin1.2, Vin1.3

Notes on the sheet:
Convertidor lineal
Regulador

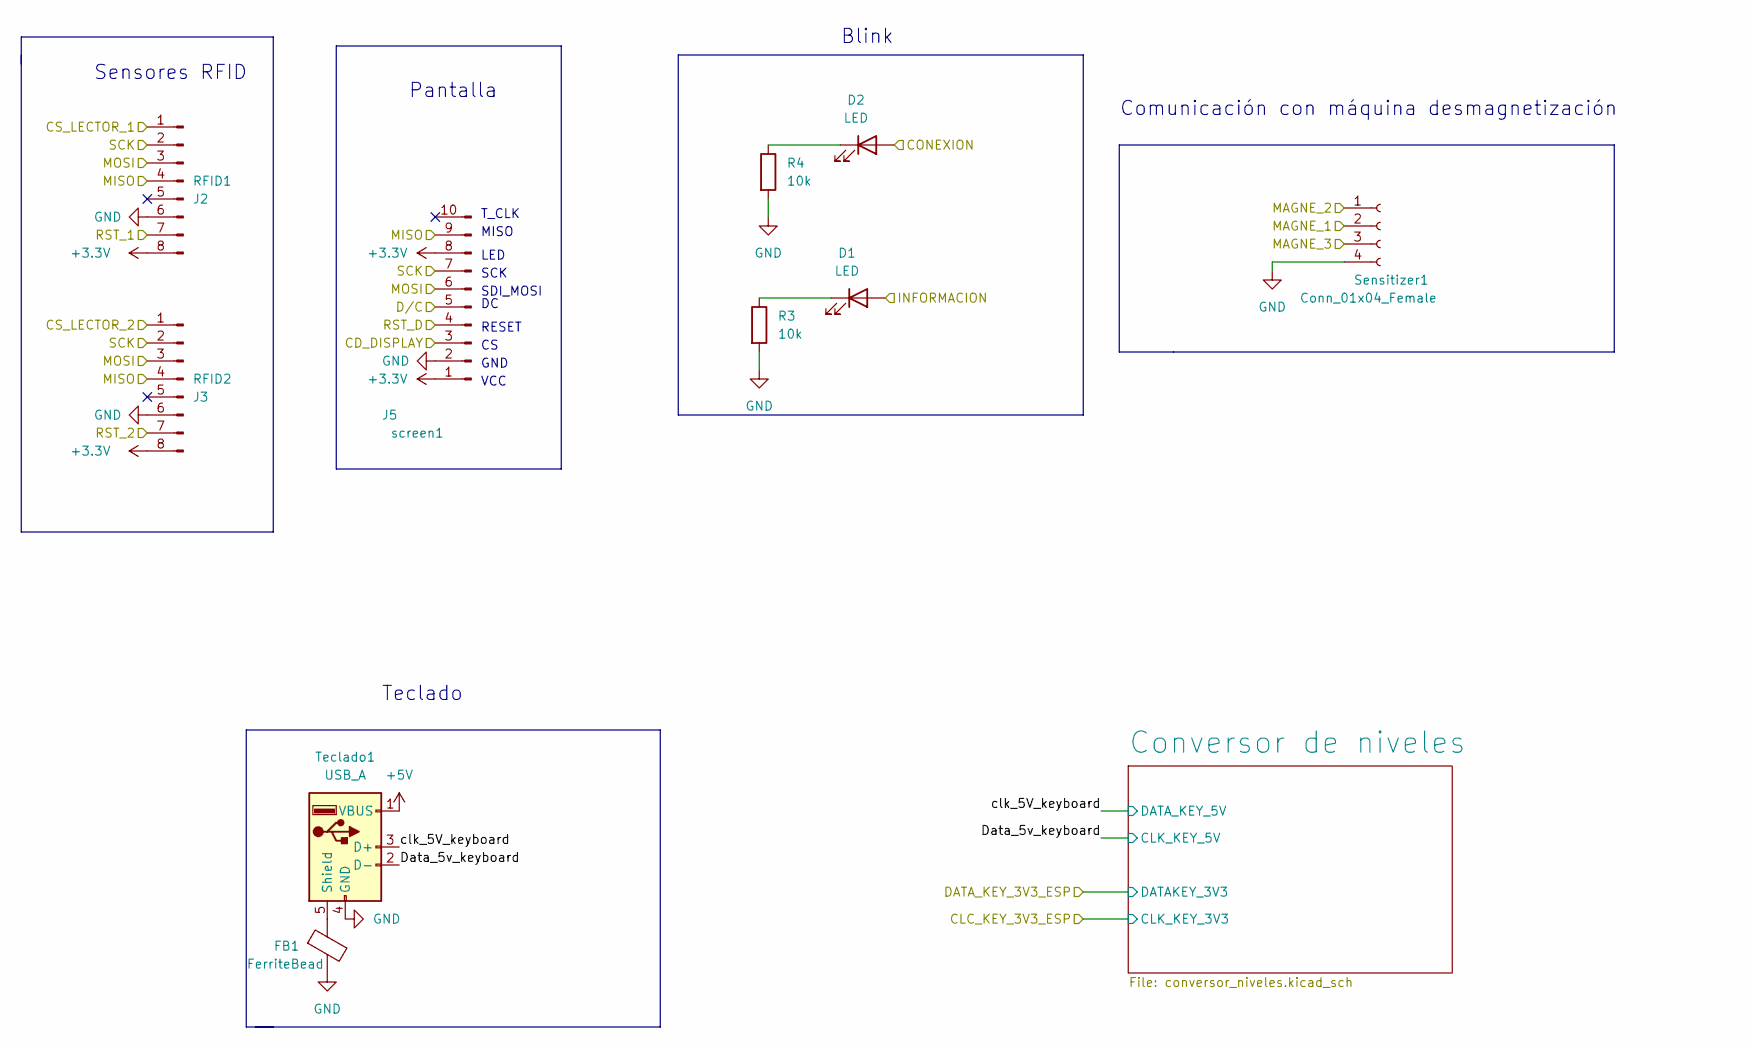
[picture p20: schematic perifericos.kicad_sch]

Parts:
D1, D2: LED; LED_0805_2012Metric_Pad1.15x1.40mm_HandSolder
FB1: FerriteBead; R_0603_1608Metric_Pad0.98x0.95mm_HandSolder
R3, R4: 10k; R_0805_2012Metric_Pad1.20x1.40mm_HandSolder
RFID1: J2; JST_EH_S8B-EH_1x08_P2.50mm_Horizontal
RFID2: J3; JST_EH_S8B-EH_1x08_P2.50mm_Horizontal
Sensitizer1: Conn_01x04_Female; JST_EH_S4B-EH_1x04_P2.50mm_Horizontal
Teclado1: USB_A; USB_A_Molex_67643_Horizontal
screen1: J5; JST_EH_S10B-EH_1x10_P2.50mm_Horizontal

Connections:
+3V3: RFID1.8, RFID2.8, screen1.1, screen1.8; also elsewhere on the board
+5V: Teclado1.1 (VBUS); also elsewhere on the board
/CONEX: D2.2 (A); also elsewhere on the board
/CS_Display: screen1.3; also elsewhere on the board
/CS_LECTOR_1: RFID1.1; also elsewhere on the board
/CS_LECTOR_2: RFID2.1; also elsewhere on the board
/D/C: screen1.5; also elsewhere on the board
/INFO: D1.2 (A); also elsewhere on the board
/MAGNE_1: Sensitizer1.2; also elsewhere on the board
/MAGNE_2: Sensitizer1.1; also elsewhere on the board
/MAGNE_3: Sensitizer1.3; also elsewhere on the board
/MISO: RFID1.4, RFID2.4, screen1.9; also elsewhere on the board
/MOSI: RFID1.3, RFID2.3, screen1.6; also elsewhere on the board
/RST_1: RFID1.7; also elsewhere on the board
/RST_2: RFID2.7; also elsewhere on the board
/RST_D: screen1.4; also elsewhere on the board
/SCK: RFID1.2, RFID2.2, screen1.7; also elsewhere on the board
/perifericos/Data_5v_keyboard: Teclado1.2 (D-); also elsewhere on the board
/perifericos/clk_5V_keyboard: Teclado1.3 (D+); also elsewhere on the board
GND: FB1.2, R3.2, R4.2, RFID1.6, RFID2.6, Sensitizer1.4, Teclado1.4 (GND), screen1.2; also elsewhere on the board
unnamed: D1.1 (K), R3.1
unnamed: D2.1 (K), R4.1
unnamed: FB1.1, Teclado1.5 (Shield)

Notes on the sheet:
Sensores RFID
MISO
Teclado
RESET
T_CLK
Pantalla
SDI_MOSI
GND
Comunicación con máquina desmagnetización
Blink
LED
SCK
VCC

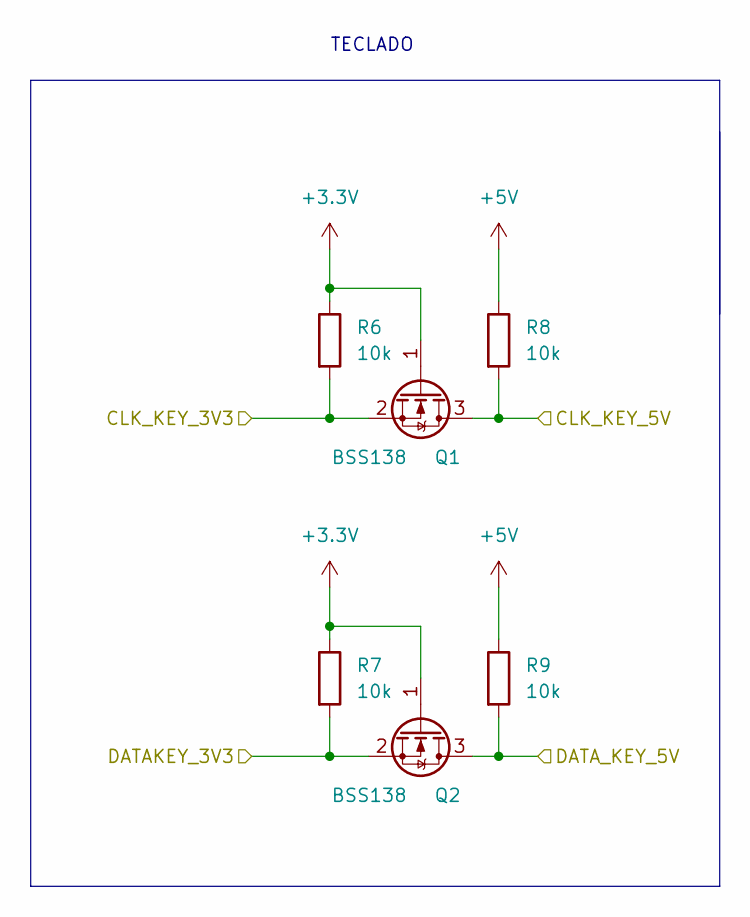
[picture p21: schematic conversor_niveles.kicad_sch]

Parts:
Q1, Q2: BSS138; SOT-23
R6, R7, R8, R9: 10k; R_0805_2012Metric_Pad1.20x1.40mm_HandSolder

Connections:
+3V3: Q1.1 (G), Q2.1 (G), R6.1, R7.1; also elsewhere on the board
+5V: R8.1, R9.1; also elsewhere on the board
/CLC_KEYBOARD: Q1.2 (S), R6.2; also elsewhere on the board
/DATA_KEYBOARD: Q2.2 (S), R7.2; also elsewhere on the board
/perifericos/Data_5v_keyboard: Q1.3 (D), R8.2; also elsewhere on the board
/perifericos/clk_5V_keyboard: Q2.3 (D), R9.2; also elsewhere on the board

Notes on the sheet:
TECLADO

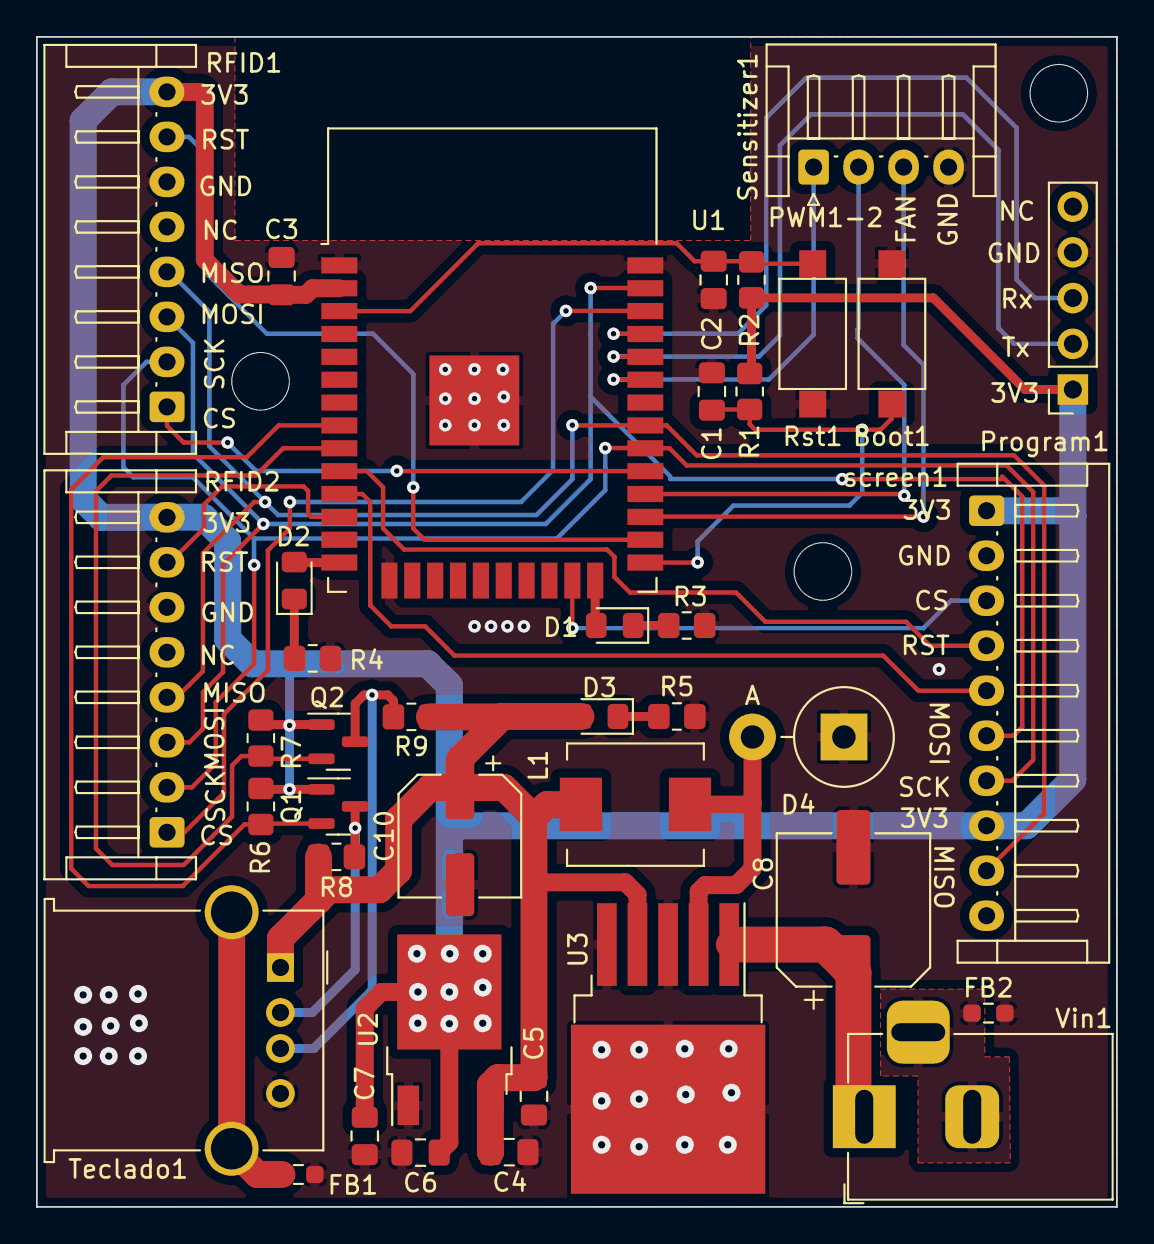
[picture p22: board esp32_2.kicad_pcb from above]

Board: 2 copper layers, 60.0 x 65.0 mm, 42 parts (0 on the bottom side), 33 nets.

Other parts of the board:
C8: 470u; CP_Elec_8x6.9
C10: 220u; CP_Elec_6.3x7.7
D4: 1N5825; D_DO-201AE_P5.08mm_Vertical_AnodeUp
L1: 68u; L_Neosid_SM-PIC0612H
T1, T2, T3: MountingHole_3.2mm_M3_DIN965
U3: LM2596S-5; TO-263-5_TabPin3

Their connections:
+5V: C10.1, L1.2, U3.4 (FB); also elsewhere on the board
+12V: C8.1, U3.1 (VIN); also elsewhere on the board
GND: C8.2, C10.2, D4.1 (K), U3.3 (GND), U3.5 (~ON/OFF); also elsewhere on the board
unnamed: D4.2 (A), L1.1, U3.2 (OUT)

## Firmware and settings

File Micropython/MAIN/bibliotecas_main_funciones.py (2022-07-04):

import perifericos
import json
import machine

from machine import SoftSPI
import math
#importar para pantalla
from time import sleep
from ili9341 import Display, color565
from machine import Pin, SPI
from xglcd_font import XglcdFont
from displayLib import MyDisplay

import teclado 
from Desmagnetizador import Desmagnetizador 

COMM=Communications()

#iniciar pantalla
disp=MyDisplay(perifericos.get_spi())

#iniciar magnetizador
magnetizer = Desmagnetizador(16,21,17) #16 fan, 21 pwm 2, 17 pwm 1

def read_json(file_name):
    with open(file_name) as IDjson:
        data = json.load(IDjson)
    return data

def write_json(file_name,data):
    with open(file_name, 'w') as IDjson:
        json.dump(data, IDjson)

def read_book_id():
    card_id_book = perifericos.lectura(2)
    while card_id_book == None :
       card_id_book = perifericos.lectura(2)
       sleep(0.5)
       print (card_id_book)
    return card_id_book

def ask_SI_for_book_info(card_id_book):
    #dic_id_book={
    #"id" : card_id_book
    #}
    #write_json('ID_book.json',dic_id_book)
    COMM.send(topic='Bibliotecas/Validate_book', ID_book=card_id_book)
    #client.publish(b'SI/Validate_book',ID_book.json,True,1)

def receive():#Revisar
        topic, message = getValues()
        if pending_incoming_message==False and  pending_incoming_message!=last_pending:
            last_topic=str(topic,'utf-8')
            last_message=message
        if (str(topic,'utf-8')!= last_topic) or (message!=last_message):
            pending_incoming_message=True
        last_pending=pending_incoming_message
        return topic, message, pending_incoming_message

def receive_MQTT():#Revisar
    topic, message, pending_incoming_message=receive()
    if pending_incoming_message==True:
        if str(topic,'utf-8')=='Bibliotecas/Validate_user':
            message_user=message
            data_json=read_json(message_user)
        elif str(topic,'utf-8')=='Bibliotecas/Validate_book':
            message_book=message
            data_json=read_json(message_book)
            
        pending_incoming_message==False
    
    return data_json

def invalid_book(book_json):
    return book_json['IDlibro'] == '0'

def show_invalid_book():
    disp.printImg('bibliotecash11.raw')

def is_borrowed(book_json):
    return book_json['current_use'] == 'True'#Esta en prestamo

def update_book_status_borrowed(book_json):#Pasa a no estar en prestamos
    book_json['current_use'] = 'False'
    return book_json

def update_book_status_no_borrowed(book_json):#Pasa a estar en prestamo
    book_json['current_use'] = 'True'
    return book_json

def send_book_info_SIGiveback(book_json_updated):
    #write_json('book.json',book_json_updated)
    #client.publish(b'SI/Give_back',book.json,True,1)
    COMM.send(topic='Bibliotecas/Give_back', book_json_updated=book_json_updated)

def send_info_SIBorrow(book_json_updated):
    #write_json('loan.json',book_json_updated,user_json)
    #client.publish(b'SI/Borrow',loan.json,True,1)
    COMM.send(topic='Bibliotecas/Borrow', book_json_updated=book_json_updated)

def no_borrowed(book_json):
    return book_json['current_use'] == 'False'#No esta en prestamo

def read_user_id():
    card_id_user = perifericos.lectura(1)
    while card_id_user == None :
       card_id_user = perifericos.lectura(1)
       sleep(0.5)
       print (card_id_user)
    return card_id_user

def ask_SI_for_user_info(card_id_user):
    #dic_id_user={
    #"id" : card_id_user
    #}
    #write_json('ID_user.json',dic_id_user)
    COMM.send(topic='Bibliotecas/Validate_user', ID_user=card_id_user)
    #client.publish(b'SI/Validate_user',ID_user.json,True,1)

def validate_user(user_json):
    return user_json['user_type'] == 'Estudiante'

def book_borrowing(user_json, book_json):
    print('Funciono')
    palabra=''
    auxiliar=''
    mensajeUsuario=''
    aux=''
    asteriscos=''

    clave_incorrecta = True
    while  clave_incorrecta:
        tecladoDisponible=True
        disp.printImg('bibliotecash1.raw')
        while tecladoDisponible:                                
            auxiliar=teclado.readLetter()
            if auxiliar==-1:
                pass
            elif auxiliar!='enter'and auxiliar!='delete':
                palabra=palabra+auxiliar
                asteriscos=asteriscos+'* '
                print(palabra)
            elif auxiliar=='delete':
                print('borra palabra')
                aux = palabra[:-1]
                asteriscos=asteriscos[:-2]
                palabra=aux
                disp.printShortText('             ')
                print(palabra)
            elif  auxiliar=='enter':
                tecladoDisponible=False
            disp.printShortText(asteriscos)
        if(palabra == user_json['clave']):
            print('clave correcta')
            palabra=''
            asteriscos=''
            clave_incorrecta = False
            disp.printImg('bibliotecash6.raw')
            magnetizer.demagnetize()
            
            disp.printImg('bibliotecash3.raw')
            sleep(3)
            disp.printImg('bibliotecash2.raw')
            book_json_updated = update_book_status_no_borrowed(book_json)
            #write_json('book.json',book_json_updated) 
            send_info_SIBorrow(book_json_updated)
            print(book_json_updated)
            
        elif (palabra != user_json['clave']):
            disp.printImg('bibliotecash5.raw')
            palabra=''
            asteriscos=''
            print('Clave incorrecta')

while True:
    COMM.check_message()
    disp.printImg('bibliotecash2.raw')
    card_id_book = read_book_id()
    ask_SI_for_book_info(card_id_book)
    book_json = receive_MQTT()
    #book_json=read_json('book.json')

    if (invalid_book(book_json)):
        show_invalid_book()
        pass

    if is_borrowed(book_json):
        magnetizer.magnetize()
        sleep(5)
        book_json_updated = update_book_status_borrowed(book_json)
        send_book_info_SIGiveback(book_json_updated)
        #write_json('book.json',book_json_updated) 
        disp.printImg('bibliotecash4.raw')
        print(book_json_updated['current_use'])

    elif no_borrowed(book_json):
        disp.printImg('bibliotecash.raw')
        card_id_user =  read_user_id()
        ask_SI_for_person_info(car_id_user)
        user_json = receive_MQTT()
        #user_json=read_json('user.json') 
        if (validate_user(user_json)):
            book_borrowing(user_json,book_json)

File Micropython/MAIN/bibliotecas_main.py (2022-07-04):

import perifericos
import json
import machine

from machine import SoftSPI
import math
#importar para pantalla
from time import sleep
from ili9341 import Display, color565
from machine import Pin, SPI
from xglcd_font import XglcdFont
from displayLib import MyDisplay
from Desmagnetizador import Desmagnetizador 

import teclado 

#COMM=Communications()

#iniciar pantalla
disp=MyDisplay(perifericos.get_spi())


#variables iniciales teclado
palabra=''
auxiliar=''
mensajeUsuario=''
aux=''
asteriscos=''
tecladoDisponible=True

#iniciar magnetizador
magnetizer = Desmagnetizador(16,21,17) #Configurar pines

def read_json(file_name):
    with open(file_name) as IDjson:
        data = json.load(IDjson)
    return data

def write_json(file_name,data):
    with open(file_name, 'w') as IDjson:
        json.dump(data, IDjson)


while True:

    disp.printImg('bibliotecash2.raw')
    card_id_libro= perifericos.lectura(2)
    if(card_id_libro != None):
        print (card_id_libro)
        data_libro = read_json('IDlibro.json')
        data_libro['id'] = card_id_libro  #ESTO SE ENVIARIA AL SI
            # COMM.send(topic='bibliotecas/Validate_libro', card_id_libro=card_id_libro)
               
        with open('prueba_libro.json') as prueba_libro:
            data_prueba_libro = json.load(prueba_libro)

        if(data_prueba_libro['IDlibro'] != "0"): 

            if ((data_prueba_libro['current_use'] == "True")):# En prestamo: TRUE, NO en prestamo:FALSE
                magnetizer.magnetize()
                sleep(5)
                data_prueba_libro['current_use']="False"
                write_json('prueba_libro.json',data_prueba_libro)
                #Enviar diccionario al SI- COMM.send(topic='bibliotecas/Validate_libro', )
                disp.printImg('bibliotecash4.raw')
          
                print(data_prueba_libro['current_use'])
                
            elif ((data_prueba_libro['current_use']=="False")):# En prestamo: TRUE, NO en prestamo:FALSE
                disp.printImg('bibliotecash.raw')

                card_id_persona= perifericos.lectura(1)
                if(card_id_persona != None):
                    print(card_id_persona)

                    with open('IDcarne.json') as IDcarne:
                        data_carne = json.load(IDcarne)
                        data_carne['id'] = card_id_persona  #ESTO SE ENVIARIA AL SI
                    
                    with open('prueba_persona.json') as prueba_persona:
                        data_prueba_persona = json.load(prueba_persona)
                        
                    
                    if(data_prueba_persona['user_type'] == "Estudiante"):
                        print('Funciono')
                        clave_incorrecta = True
                        while  clave_incorrecta:
                            tecladoDisponible=True
                            disp.printImg('bibliotecash1.raw')
                            while tecladoDisponible:                                
                                auxiliar=teclado.readLetter()
                                if auxiliar==-1:
                                    pass
                                elif auxiliar!='enter'and auxiliar!='delete':
                                    palabra=palabra+auxiliar
                                    asteriscos=asteriscos+'* '
                                    print(palabra)
                                elif auxiliar=='delete':
                                    print('borra palabra')
                                    aux = palabra[:-1]
                                    asteriscos=asteriscos[:-2]
                                    palabra=aux
                                    disp.printShortText('             ')
                                    print(palabra)
                                elif  auxiliar=='enter':
                                    tecladoDisponible=False
                                disp.printShortText(asteriscos)
                            if(palabra == data_prueba_persona['clave']):
                                print('clave correcta')
                                palabra=''
                                asteriscos=''
                                clave_incorrecta = False
                                disp.printImg('bibliotecash6.raw')
                                magnetizer.demagnetize()
                                sleep(6)
                                disp.printImg('bibliotecash3.raw')
                                sleep(3)
                                disp.printImg('bibliotecash2.raw')
                                data_prueba_libro['current_use']="True"
                                write_json('prueba_libro.json',data_prueba_libro)
                                print(data_prueba_libro)
                                #Enviar diccionario actualizado a la SI, Id libro y id user para vincular
                            elif (palabra != data_prueba_persona['clave']):
                                disp.printImg('bibliotecash5.raw')
                                palabra=''
                                asteriscos=''
                                print('Clave incorrecta')
                    else:
                        print('No es estudiante')                    
                else:
                    print('No ha sido leido el carne')
            else:
                print('El estado del libro no es claro')
        else:
            print('No se ha asignado el ID del libro al json del libro') 
   
    else:
        print('No ha sido leido el libro')
    sleep(1)   
        

 

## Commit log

2022-05-10 PCB para el sensibilizador
    Se añade archivos de Kicad para la PCB del sensibilizador, así como librerías para el driver LM5104M
    [BookSensithyzer.kicad_pcb, BookSensithyzer.kicad_sch, LM5104M.step]
2022-05-10 Corrección
    [BookSensitizer.kicad_pcb, BookSensitizer.kicad_sch]
2022-05-10 pequeño cambio
    [BookSensitizer.kicad_sch]
2022-05-10 Sensibilizador con valores
    Se agregaron valores a los elementos de los drivers y se modificó la topología.
    [BookSensitizer.kicad_pcb, BookSensitizer.kicad_sch]
2022-05-10 check list del diseño driver puente H
    [LM5109B Schematic Review Template.xlsm]
2022-05-12 huellas agregadas
    [BookSensitizer.kicad_sch, LM5104M.step, LM5109B Schematic Review Template.xlsm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]
2022-05-12 Rectificador primera versión
    [BookSensitizer.kicad_sch, GBPC3506.step, Mosfet_driver.kicad_sch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]
2022-05-16 Listo pa tirar lineas
    [BookSensitizer.kicad_pcb, BookSensitizer.kicad_sch, Mosfet_driver.kicad_sch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]
2022-05-16 Organizado 0 aire
    0 aire
    ready pa rutear
    [BookSensitizer.kicad_pcb]
2022-05-16 mini cambio en label de RHon
    [BookSensitizer.kicad_pcb, BookSensitizer.kicad_sch, Mosfet_driver.kicad_sch]
2022-05-16 la mitad de los trazos
    [BookSensitizer.kicad_pcb]
2022-05-16 PCB lista
    [BookSensitizer.kicad_pcb]
2022-05-16 Con tornillos
    [BookSensitizer.kicad_pcb]
2022-05-17 mini arreglo para conectar una tierra
    [BookSensitizer.kicad_pcb]
2022-05-17 Version ruteada
    [Regulador.kicad_sch, conversor_niveles.kicad_sch, esp32_2.csv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]
2022-05-17 borrarndo todo
    [Regulador.kicad_sch, conversor_niveles.kicad_sch, esp32_2.csv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]
2022-05-17 listo para rutear la ESP
    [Regulador.kicad_sch, conversor_niveles.kicad_sch, esp32_2.csv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]
2022-05-18 prueba de cambios
    [esp32_2.kicad_sch]
2022-05-18 ruteo listo con un posible error en footprint esp32
    [esp32_2.csv, esp32_2.kicad_pcb, esp32_2.kicad_sch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]
2022-05-18 correción de un pulsador
    [Regulador.kicad_sch, esp32_2.kicad_pcb, esp32_2.kicad_sch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]
2022-05-18 se agregaron los valores (pendiente última revisión)
    [Regulador.kicad_sch, conversor_niveles.kicad_sch, esp32_2.kicad_sch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]
2022-05-19 diseño listo
    [esp32_2.kicad_pcb]
2022-05-20 Correciones de la clase
    [Regulador.kicad_sch, esp32_2.kicad_pcb, esp32_2.kicad_sch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]
2022-05-20 huecos listos
    [esp32_2.kicad_pcb, esp32_2.kicad_sch, funcionamiento.kicad_sch]
2022-05-20 placa terminada
    [BookSensitizer.kicad_pcb, Regulador.kicad_sch, esp32_2.kicad_pcb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]
2022-05-20 Gerber Generados
    [BookSensitizer-B_Cu.gbr, BookSensitizer-B_Mask.gbr, BookSensitizer-B_Paste.gbr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]
2022-05-21 ajuste final
    [esp32_2-B_Cu.gbr, esp32_2-B_Mask.gbr, esp32_2-B_Paste.gbr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]
2022-06-02 boom creado
    [BookSensitizer.csv]
2022-06-03 lista de materiales
    [Lista_materiales.xlsx, esp32_2.csv, esp32_2.kicad_sch]
2022-06-03 Lista de compras
    [Lista_materiales.xlsx]
2022-06-03 Actualización lista de materiales
    [Lista_materiales.xlsx]
2022-06-05 compras bogotá
    [Lista_materiales.xlsx]
2022-06-10 ValoresCorregidos
    Algunos valores de resistencias fueron corregidos y coinciden con la placa.
    Valores de resistencias en los leds.
    [BookSensitizer.kicad_sch, Mosfet_driver.kicad_sch, ventilador.kicad_sch]
2022-06-10 arreglos carcasa
    [Ensamble caja.0003.iam, Ensamble caja.iam, Fondo.0002.ipt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]
2022-06-17 Carcasa final
    [Ensamble caja.0004.iam, Ensamble caja.iam, Fondo.0003.ipt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]
2022-06-19 Archivos de simulación bobina
2022-07-02 actualizacion de eclado
2022-07-04 comprobacion de contraseña
2022-07-05 Simulacion Magnetizador Terminada
